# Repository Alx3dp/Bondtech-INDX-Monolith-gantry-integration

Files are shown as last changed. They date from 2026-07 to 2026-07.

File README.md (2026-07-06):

# Bondtech INDX Monolith gantry integration
This is a repository of various mods to make the Bondtech INDX toolchanging system compatible with the Monolith gantry and add features to it.

My modifications are based either off of the official reference models from Bondtech https://github.com/BondtechAB/INDX for the toolhead, or Monolith for the gantry parts: https://github.com/Monolith3D/Monolith_Gantry

Since every printer is different I have organised this repository with modularity in mind, here is soem general information, you will find more detailed information or hardware BOM'S in the relevant folders.

# 0 - Unchanged INDX reference parts
You do not need to print any parts from this folder, the contents are only there as reference if you want to make a CAD model for your specific configuration. These are the parts of the INDX toolhead that are not modified, everything here is included when you order the toolhead.

# 1 - Belt clamp
This is the belt clamp connecting the x carriage, the belts and the toolhead.
In case you want to use a nozzle camera choose the appropriate sub folder as the mount for those is integrated into this part.

You only need the contents of one sub folder.

# 2 - Scanning probe mount
This is an attachment for various scanning Z probes.
It is not strictly necessary as the INDX Toolhead already has a integrated loadcell as a Z-probe, but scanning Z probes like the various versions of beacon and cartographer or the one from Bondtech specifically intended for the INDX system still provide a significant quality of life benefit, like rapid bed meshing. 

The mounts also have a mount for a X endstop integrated and provide adittional support to the nozzle cam if you choose that option.

You only need the contents of the one sub folder for your specific probe, if you do not use any scannign probe you do not need any of these mounts.

# 3 - Cooling ducts
These are the cooling duct options. They are specifically designed to not decrease the minimum distance between tools and not impact xy travel.
You can still choose to go with the official Bondtech ducts, however be aware that they increase the minimum tool to tool distance from ~34mm to ~40mm
You can find the bondtech ducts here: https://github.com/BondtechAB/INDX/tree/main/CAD/STL
If you do decide to go with them, you do not need anything from this folder, otherwise you only need the contents of one sub folder.

# 4 - Tool holders
These are various options for the front 1515 beam on which the tools are mounted.
You will find more information in the readme in the folder, but once again you only need the contents of one sub folder

# 5 - Miscellaneous
Lastly "the other stuff", basically optional or quality of life parts that do not fit in the other categories, check the readme in the folder for more details.

# future plans:

No protrusion versiopns fo the toolbar, so that it is also compatible with stock 2020 Voron frames and panels

6mm belt compatibility

# Licenses
Because Monolith3d and Bondtech use different licenses there is no overarching license for this entire project.
Instead you will find the relevant licenses in the folders dependiong on from where I got the original parts I modified.
If that is an issue in some way please contact me.

# contact
If you have questions, feature requests or notice any issues feel free to contact me.
Eiter via email at alx.3dp@gmail.com, @ me in the Bondtech discord server, the project thread in the Monolith discord server or just write me a DM to alx1234

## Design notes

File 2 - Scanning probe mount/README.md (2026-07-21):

# Scanning Z probe mounts

Important: Cartographer V3 and beacon revD only is compatible with the mounts with Nozzle cam in the right angle configuration while Beacon revH is only compatible with it in the regular configuration, not the low profile one.
If you have the regular or low profile versions you need to resolder it to be right angle.
However he regular version definitly works with the no nozzle cam mount, the low profile one might but you will need to bend the wires quite sharply.

As of right now there are only options for the Beacon and Cartographer probes, I am planning to make a version for the INDX custom one but will wait until it is released so that I can confirm dimensions of it.

The Beacon/cartographer mounts should be compatible with all versions of these probes that have the cables going upwards, so the low profile versions are not compatible.

If you have a different probe you wish to use contact me and I will see what I can do, contact details are in the main readme.

# BOM

All versions:
2 m3x5x4 Heat set inserts |  same as what Voron and most others use, used to mount the z probe

2 m3x4-6 screws | used to mount the Z probe

d2f or similar microswitch | This is used for the X endstop, if you use another endstop or sensorless homing you do not need this

2 m2x8-10 self tapping screws | Used to mount the microwsitch

Additionally for the versions with nozzle camera:
2 m3x5x4 Heat set inserts |  used for the nozzle cam mount

# probe offsets

Beacon/carto without nozzle cam:
X: -38 mm
Y: 0mm

Beacon/carto with nozzle cam:
X: -48 mm
Y: 0mm

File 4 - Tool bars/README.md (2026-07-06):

# Toolholder

The toolholder is optimised to need less space in front of the toolbar and make toolbar mountign easier.

You need the same hardware as the regular bondtech tool holders, 
except the screw which is m3x6 FHCS instead of m3x :

1x m3x6 FHCS | used to screw the tool holder to the toolbar

1x m3 square nut | used to screw the tool holder to the toolbar

1x spring 6mm OD 0.4mm wire diameter 25mm length | used for the magnet holder

1x 5x8mm round magnet | the stronger the better

2x 3x8mm magnets | the stronger the better

# Tool bars

The toolbar is a 1515 aluminum extrusion on which the tool holders are mounted.

The tool holders are designed for minimal Y-travel loss and do not protrude beyond the motor mounts, so if you cant have anythign btrotruding beyond the frame either use the NP Monolith front motor mounts with the awd toolbar or the NP parts for 2wd.

Since Monolith Awd gantries already have mounting holes intended for such a purpose, you can mount the toolbar with just 2 adapter pieces, same for 2wd though there the adapter pieces are bigger and go into the front idler mounting holes, check the cad if you want to know more.

The awd version is fully compatible with the LDO CNC Monolith kits, however the 2wd is not since the cnc uses different thicknesses on the front idlers, however that would be a relatively easy change to make.
# BOM:

Awd and 2wd:

2x m3x6 FHCS | used to attach the 1515 beam to the adapters

2x m3 square nuts | used to attach the 1515 beam to the adapters

optional: you can tap the 1515 extrusion and use a m3 screws through there for added strength, however that will make assembly and disassembly a bit harder 

Awd specific:

1515 aluminum extrusion 
    for a standard 350mm: 370mm
    for a standard 300mm: 320mm
    for a standard 250mm: ~70mm

4x m3x5x4 heat set inserts | used to mount the toolbar to the motor mounts

4x m3x6-12 | used to mount the toolbar to the motor mounts

2wd specific:

1515 aluminum extrusion 
    for a standard 350mm: ~410mm
    for a standard 300mm: ~360mm
    for a standard 250mm: ~310mm

2wd fixed gantry specific:

4 screws used to mountign the idlers to teh gantry are replaced by 4mm longer ones
    on 6mm belts version:   4x M5x16 replaced by 4x M5x20
    on 9/10mm belts version: 4x M5x10 replaced by 4x M5x14

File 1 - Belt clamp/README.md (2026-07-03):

# Belt clamp

The Belt clap design is based off of the official Monolith belt clamp you can find here: https://github.com/Monolith3D/MISC/tree/main/Monolith_SLM_belt_clamps

I redesigned it a little to make it compatible with the INDX toolhead, it allows up to 12mm wide belts.
I would recommend using the strongest material you can for this part since the walls of the screw holes need to be quite thin due to the way the toolhead is designed, I personally use annealed pet-gf.

To reach higher belt tensions that increase imput shaper performance and therefor maximum usable acelleration I highly recommend using a pretensioner to tension and fix the belts in place when installing the belt clamp, best ask in the Monolith discord and someone will probably be able to point you towards one, I will make my own design at some point as well.  

If you want to use a Nozzle camera you need to choose the appropriate folder since the camera mount is integrated into the belt clamp.

# BOM
No matter which version you choose, you will need: 

4 m3x6 FHCS screws | these screws are used to attach the beltclamp to the MGN12 carriage and to secure the  belts to the belt clamp prior to installing the actual toolhead using the belt clamp plate.

The Screws to mount the actual toolhead to the Belt clamp will be added once I have received th toolhead and verified the lengths. If this is still here after the 19th of July 2026 I ahev forgot so please contact me to remind me...

Nozzle cam specific BOM:

2 m3x8-10 screws | used to secure the nozzle cam mounting parts 

# Nozzle cam
I use a cheap camera module from Ali express and that is what I modeled the camera mount after, so no guarantees it will fit.

It is designed to be used with 2 small rbg leds I had from my XOL toolhead, you can find them here:
https://www.replimat.eu/4x-rgbw-sequins-for-xol-minisb/rt10179
You can probably find them elsewhere as well.
If you want another lighting option contact me and I will see what I can do though the space is very limited.

The 3DO nozzle cam V2 is not compatibel with the current mount since it uses a custom sensor mounting pcb and I havent yet bothered to design something for it. If you want to use this, either make your own mount (and please send me the step file so that I can add it here) or contact me and i will see if I can make it, the contact details are in the main readme.

The original 3DO nozzle cam (non V2) *probably* works, as should most others that are just the small camera module mounted on a ribbon cable, but no guarantees.

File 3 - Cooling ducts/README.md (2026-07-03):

# Cooling ducts

These are fully custom Coolign ducts I designed together with CFD analysis.
The main design goal was to make cpap cooling ducts that do not increase the tool to tool distance while providing good cooling performance.
Unlike the stock Voron gantry, on Monolith there is unused space behind that X-beam, so that is used by having the duct wrap around the X beam insead of the sides of the toolhead like with the stock ducts from Bondtech.

The current 2 options are either for a regular 2020 aluminum extrusion (or any other beam that has nothign protrude behind that) and the Carbonara CF-beam that has screws with nuts protruding behind it, for which there is a cutout in teh duct.

That *might* harm airflow a bit by creating an extra restriction but I don not believe it is too significant.

If you have any other option, like a backer behind the beam for example, contact me and I will see what I can do, contact details are in the main readme. 

# BOM

for all versions:

2 m3x5x4 Heat set inserts | used to connect the 2 duct pieces

2 m3x8-10 screws | used to connect the 2 duct pieces

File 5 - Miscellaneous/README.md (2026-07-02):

# Miscellaneous

These are jsut parts that do not fit really in any other category.

# motor cover with nozzle cam pcb mount

this is a motor cover with a mount for the specific camera pcb I am using, I can not guarantee it will work for others.

As of right now it is in general untested.

BOM:

2 m2.5x6 screws | used to mount the camnera pcb

The relevant licenses can be found in the folders.

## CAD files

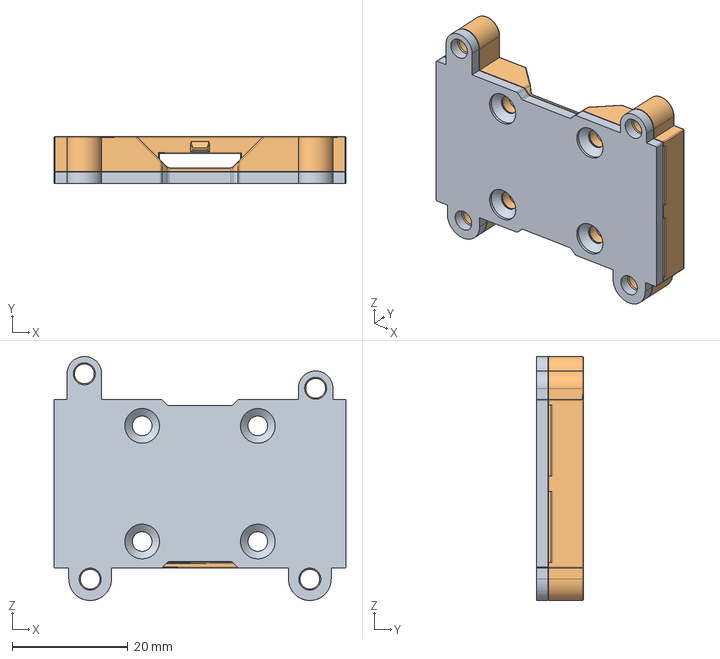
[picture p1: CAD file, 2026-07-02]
1 - Belt clamp/1.1 - without nozzle cam compatibility/INDX_Monolith_belt_clamp.step
50.5 x 8.18 x 42.2 mm

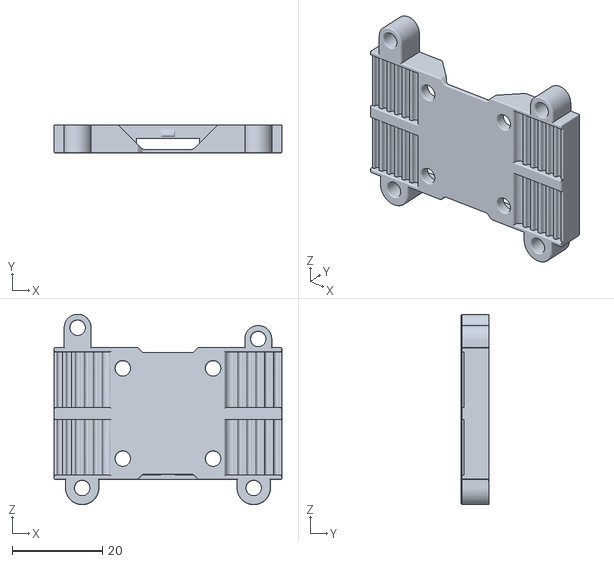
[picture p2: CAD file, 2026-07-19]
1 - Belt clamp/1.1 - without nozzle cam compatibility/Printed parts/Belt clamp.stl
50.5 x 6.24 x 42.2

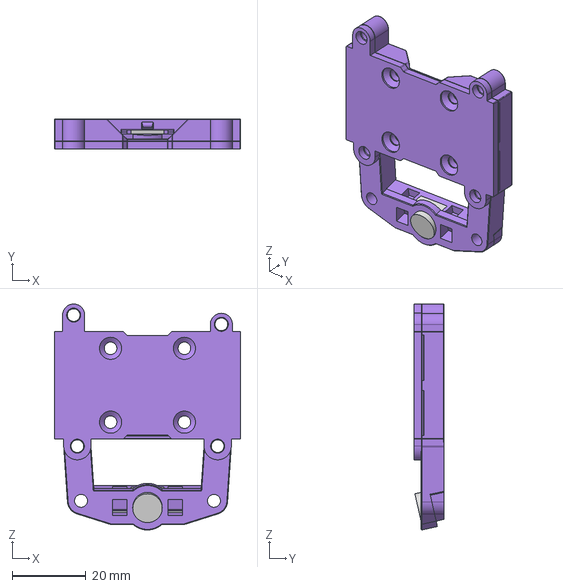
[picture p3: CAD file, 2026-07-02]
1 - Belt clamp/1.2 - with nozzle cam compatibility/INDX_Monolith_belt_clamp_cam.step
50.5 x 8.18 x 61.2 mm

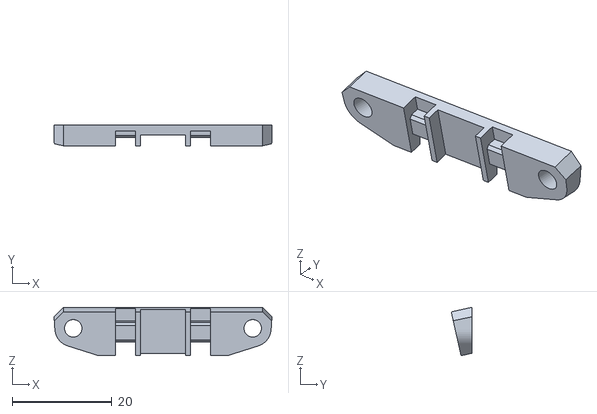
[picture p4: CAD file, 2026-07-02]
1 - Belt clamp/1.2 - with nozzle cam compatibility/printed parts/nozzle cam fixture.stl
43.7 x 4.12 x 9.71

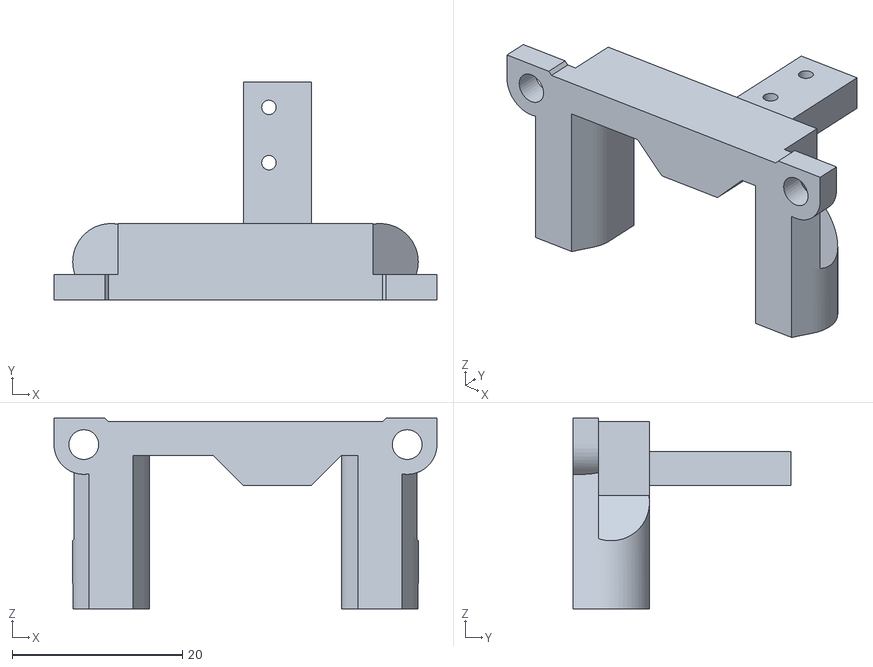
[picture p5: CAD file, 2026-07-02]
2 - Scanning probe mount/2.1 - Beacon+cartographer probe without nozzle cam/Printed parts/scanner mount.stl
45.0 x 25.7 x 22.4

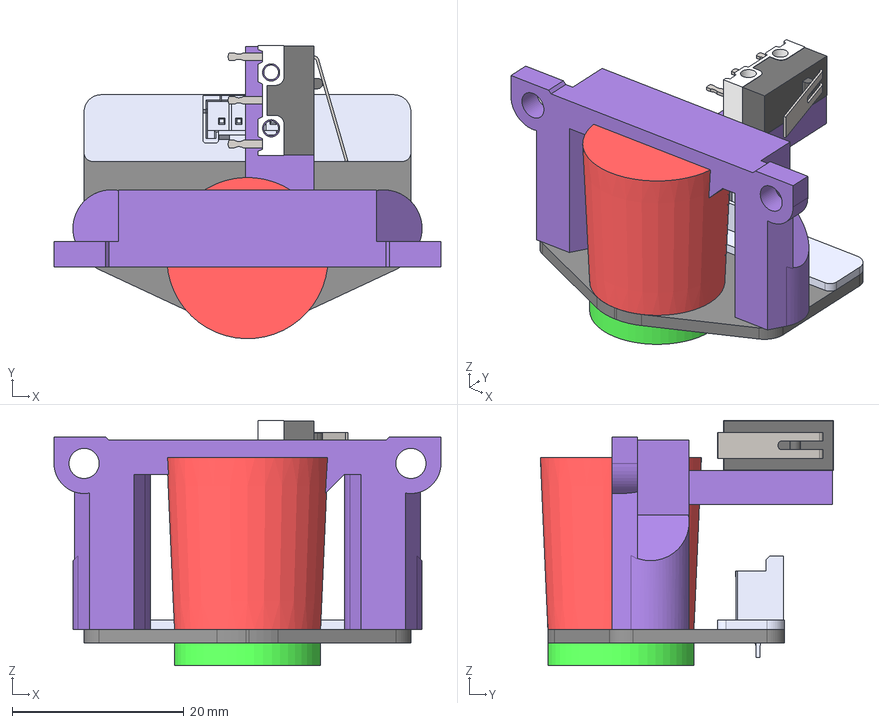
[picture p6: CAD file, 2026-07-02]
2 - Scanning probe mount/2.1 - Beacon+cartographer probe without nozzle cam/Scanner mount.step
45.0 x 34.1 x 28.5 mm
BeaconG_LP
D2F-01L

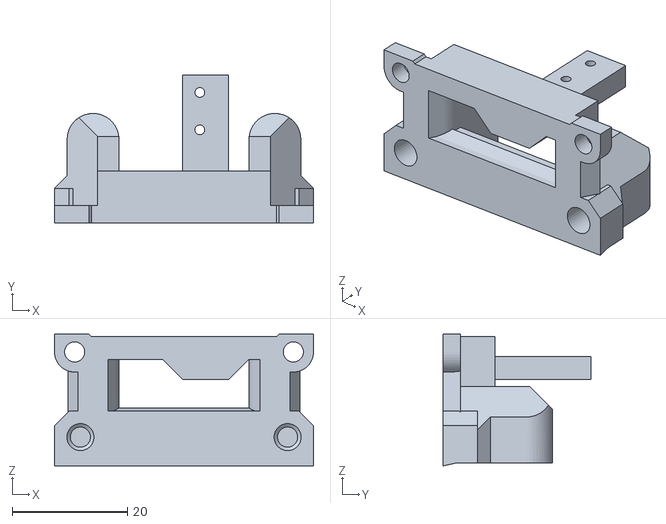
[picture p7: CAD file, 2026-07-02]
2 - Scanning probe mount/2.2 - Beacon+cartographer probe with nozzle cam/Printed parts/Scanner mount with nozzle cam.stl
45.0 x 25.7 x 22.9

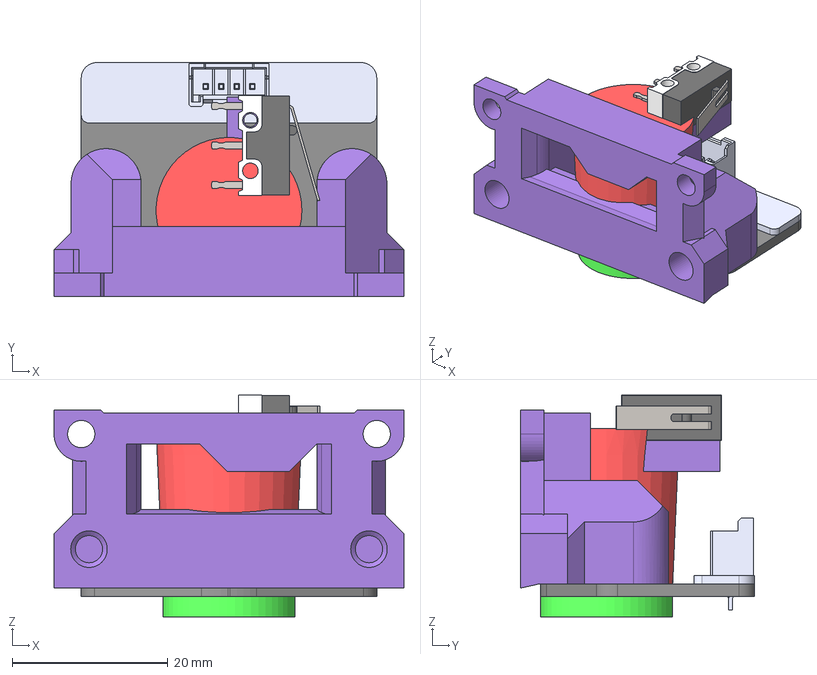
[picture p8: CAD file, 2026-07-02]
2 - Scanning probe mount/2.2 - Beacon+cartographer probe with nozzle cam/Scanner mount with nozzle cam.step
45.0 x 30.1 x 28.5 mm
BeaconG_LP
D2F-01L

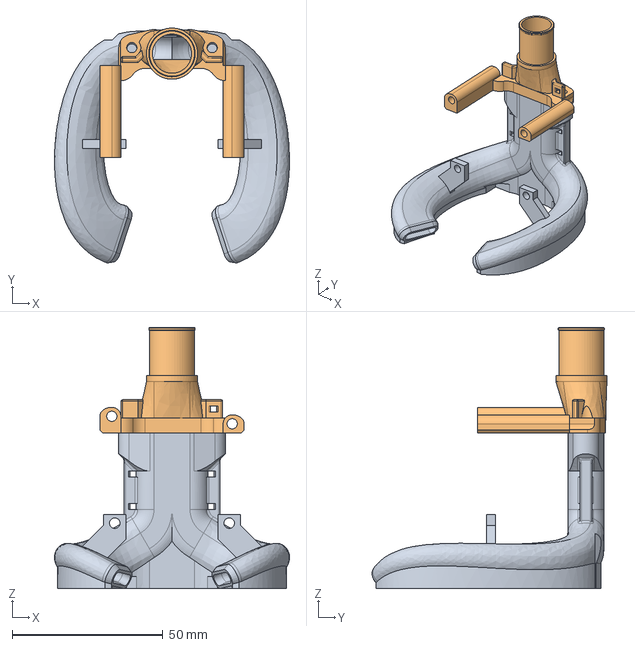
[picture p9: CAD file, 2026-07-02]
3 - Cooling ducts/3.1 - cpap ducts for 15mm ID hose and regular 2020 x-beam/INDX monolith duct.step
78.1 x 78.0 x 86.7 mm

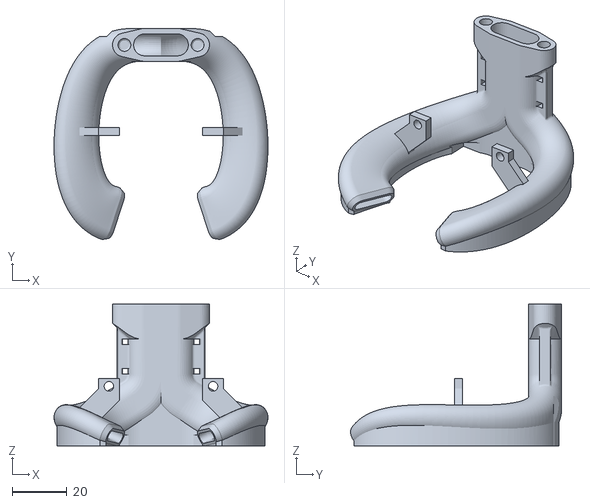
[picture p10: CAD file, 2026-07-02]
3 - Cooling ducts/3.1 - cpap ducts for 15mm ID hose and regular 2020 x-beam/printed parts/Duct lower.stl
78.1 x 77.0 x 51.7

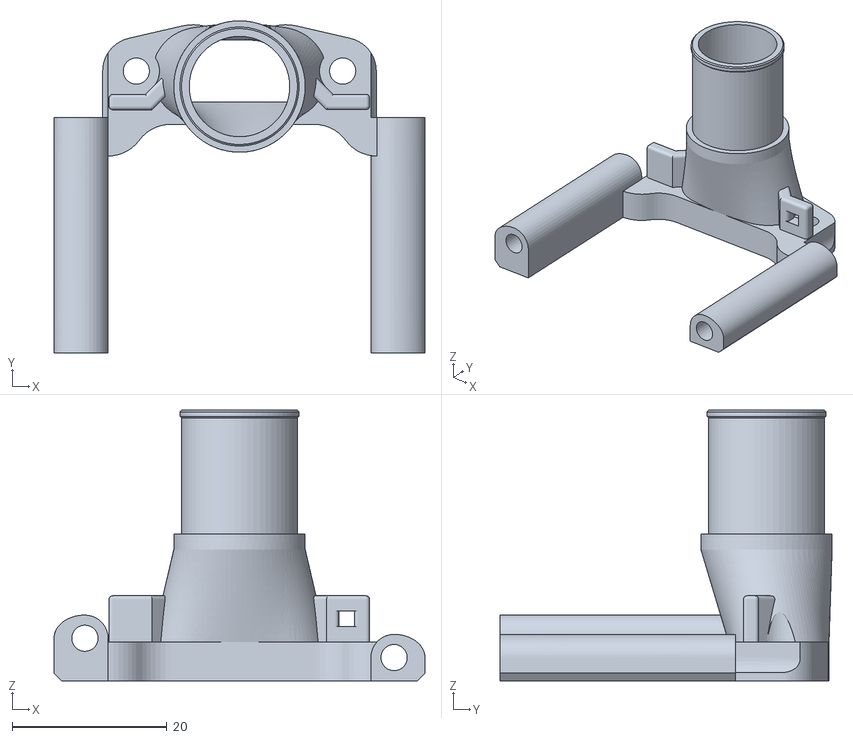
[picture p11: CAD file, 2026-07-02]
3 - Cooling ducts/3.2 - cpap ducts for 15mm ID hose and carbonara CF x-beam/printed parts/duct upper.stl
48.0 x 43.0 x 35.0

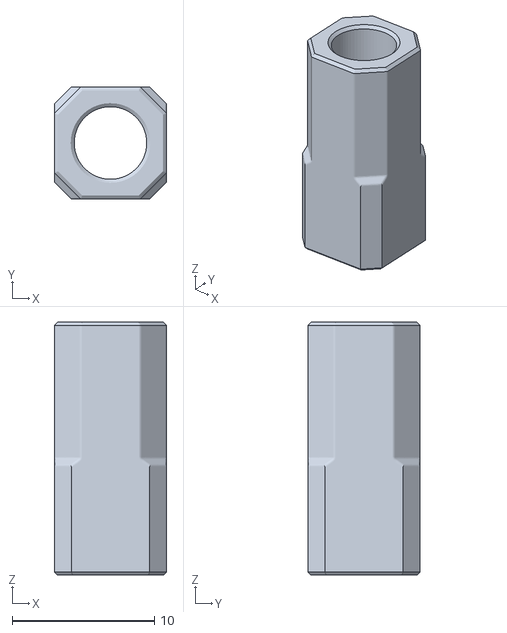
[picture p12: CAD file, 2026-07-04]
4 - Tool bars/4.0 toolholder/printed parts/Magnet holder.stl
7.90 x 7.90 x 17.8

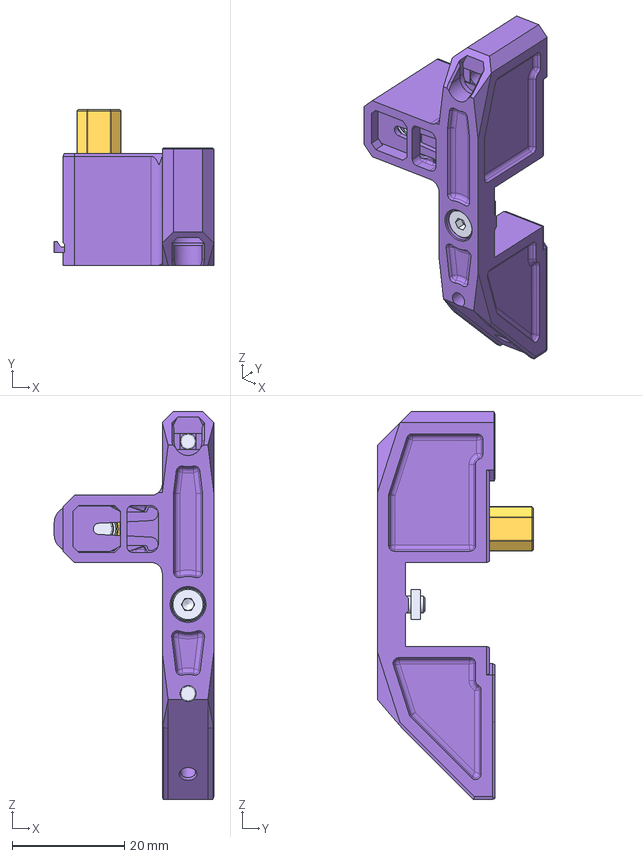
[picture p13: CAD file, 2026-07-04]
4 - Tool bars/4.0 toolholder/tool holder.step
28.5 x 27.9 x 69.3 mm
INDX Tool Dock Universal 1515 Bar_Tool holder body
INDX Tool Dock Universal 1515 Bar_Activator Magnet holder
S-03-08-N x 2
S-05-08-N
Lesjöfors 2296_Komprimerad
INDX Tool Dock Universal 1515 Bar_Spring lid
MC6S_M3X10OBEH
FKM Fyrkantsmutter

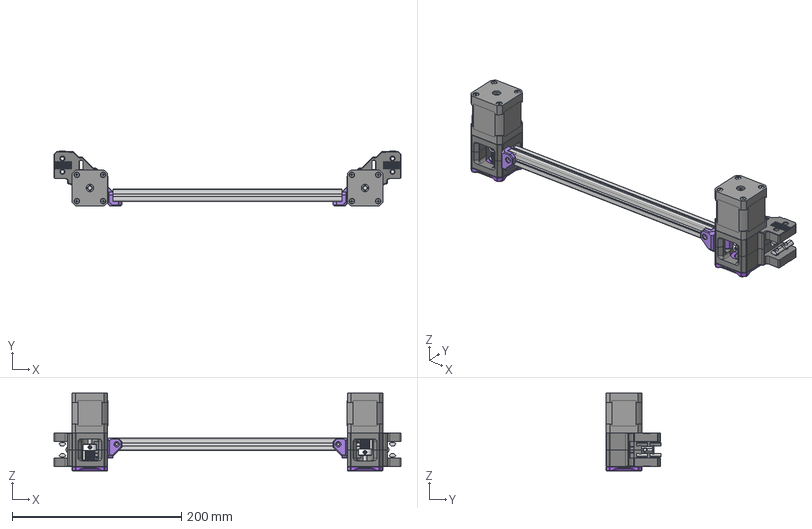
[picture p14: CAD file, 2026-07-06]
4 - Tool bars/4.1 awd/CAD/flying gantry/9mm/Monolith INDX Toolbar 250mm AWD 9mm flying gantry.step
410.0 x 64.6 x 92.0 mm
Printed_V2_9mm_front_motor_mount_a x 2
Printed_V2_9mm_front_motor_mount_b x 2
GT2 20T 9mm pulley x 2
F695 flanged bearing x 6
Shim 0.5mm x 8
695 bearing x 2
D5x40 smooth pin x 2
M5 2020 drop-in T-nut x 10
M5x10 BHCS x 2
M5 washer x 2
Printed_long_shaft_double_shear_twist_lock x 2
M3x45 SHCS x 8
M3 washer x 8
Printed_long_shaft_double_shear_housing x 2
_S45R shaft x 2
_stepper x 2

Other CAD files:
3 - Cooling ducts/3.2 - cpap ducts for 15mm ID hose and carbonara CF x-beam/INDX monolith duct Carbonara.step
4 - Tool bars/4.1 awd/Printed parts/Monolith INDX awd tool bar mount left.stl
4 - Tool bars/4.2 2wd for printed/6mm belts/fixed gantry/CAD/Monolith INDX Toolbar 250mm 2WD 6mm fixed gantry.step
4 - Tool bars/4.2 2wd for printed/6mm belts/fixed gantry/printed parts/FT/FT Toolbar connector left.stl
1 - Belt clamp/1.1 - without nozzle cam compatibility/Printed parts/belt clamp plate.stl
1 - Belt clamp/1.2 - with nozzle cam compatibility/printed parts/belt clamp plate.stl
1 - Belt clamp/1.2 - with nozzle cam compatibility/printed parts/belt clamp with nozzle cam.stl
3 - Cooling ducts/3.2 - cpap ducts for 15mm ID hose and carbonara CF x-beam/printed parts/Duct lower Carbonara.stl
4 - Tool bars/4.0 toolholder/printed parts/Toolholder.stl
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

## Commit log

2026-07-02 Creation of the Repository
    [Duct lower Carbonara.stl, Duct lower.stl, Front idler flying gantry lower left.stl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]
2026-07-04 Fixed awd+custom toolholders
    Fixed the issue with the toolholder spacign I noticed earlier on AWD, the problem still exists on 2wd.
    I also added custom optimised toolholders
    [Magnet holder.stl, Monolith INDX Toolbar 250mm AWD flying gantry.step, Monolith INDX Toolbar 300mm AWD flying gantry.step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]
2026-07-06 Fixes+ 2wd toolbars added
    Fixed the prior issue with the 2wd toolbar and added general 2wd support
    [FT Toolbar connector left.stl, FT Toolbar connector right left.stl, FT Toolbar connector right.stl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]
2026-07-19 added missing stl
    added a previously missign stl for the Beltclap without nozzle compatibility
    [Belt clamp.stl]
